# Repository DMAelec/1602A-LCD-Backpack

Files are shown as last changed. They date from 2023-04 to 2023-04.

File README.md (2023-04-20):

# 1602A LCD Backpack

## Introduction
The 1602A LCD Backpack is a AVR(ATMEGA328) microcontroller module that mounts behind standard 16 character x 2 column LCD displays.
It is essentially an Arduino Uno with a built in LCD and some other extra features. The boards are designed using SMD parts
to reduce component size so proper tools are required.

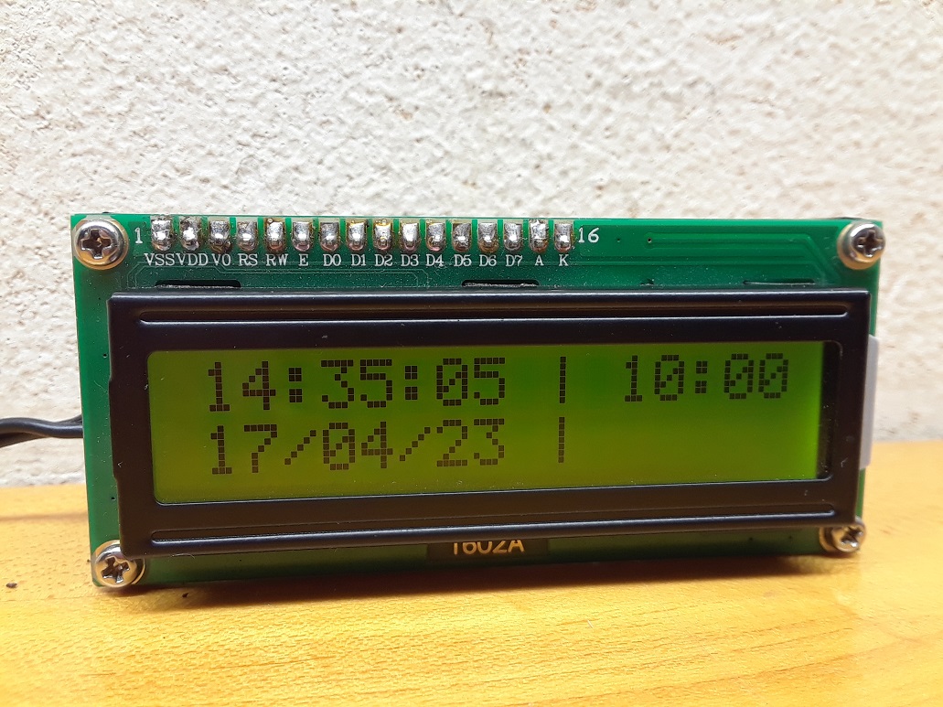
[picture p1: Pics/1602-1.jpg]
1602A Running


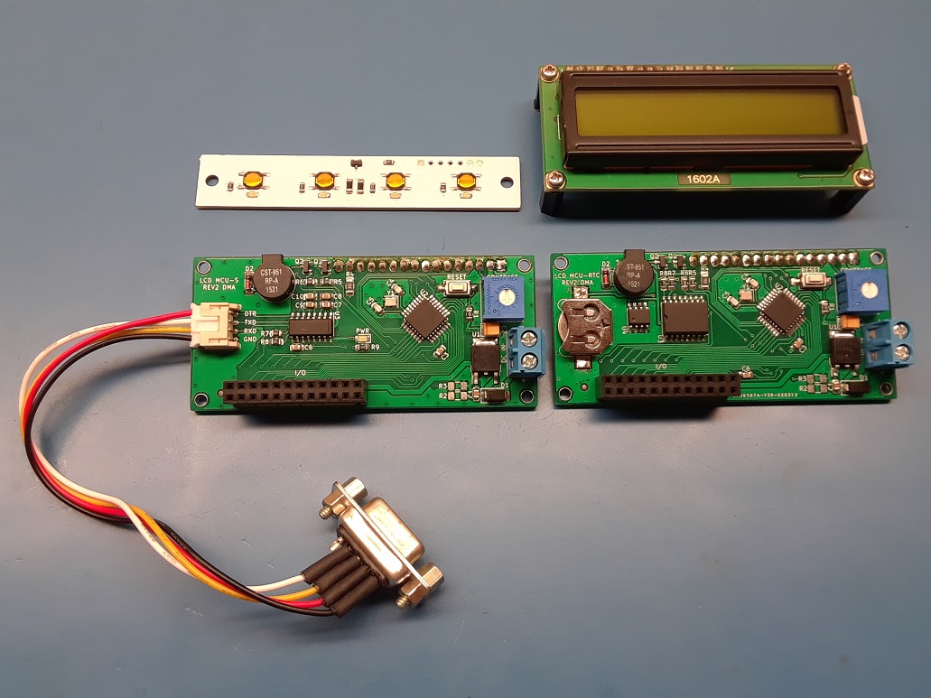
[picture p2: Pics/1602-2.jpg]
1602A Boards


## Features
There are two variants of the backpack in this repo. One with a DS3231 I2C RTC including a I2C EEPROM useful for data logging,
and the other variant with a MAX232 RS232 interface IC. Both boards share features like a optional PWM backlight, speaker, 
and analog volt meter using a simple divider. These can be obmitted if not needed as all pins are brought out to a IO pinheader and
repurposed for other uses. Also included in this repo are external button boards for user input and a blank board for future attachments.

### Board List and features

* 1602A_LCD-RTC Backpack
  * PWM backlight
  * On board speaker
  * Analog voltage monitor
  * I2C real time clock
  * I2C EEPROM

* 1602A_LCD Serial Backpack
  * PWM backlight
  * On board speaker
  * Analog voltage monitor
  * RS232 serial interface with auto reset

* 1602A_Blank
  * Blank board outline for future additions

* BTNPAD_ANALOG_READ
  * Single wire 5 button board using a resistor network

* BTNPAD_TYPE_A
  * 4 button board with pullup resistors

* BTNPAD_TYPE_B
  * 4 button board with pullup resistors
  * LED backlit buttons

## Hardware Documentation

### Schematics

[1602A_LCD-RTC Schematic](/1602A_LCD-RTC%20Backpack/1602A_LCD-RTC%20%20Backpack-SCHEMATIC.pdf)

[1602A_LCD Serial Schematic](/1602A_LCD%20Serial%20Backpack/1602A_LCD%20Serial%20Backpack-SCHEMATIC.pdf)

[BTNPAD_ANALOG_READ Schematic](/Button%20Pad/BTNPAD_ANALOG_READ/BTNPAD_ANALOG_READ-SCHEMATIC.pdf)

[BTNPAD_TYPE_A Schematic](/Button%20Pad/BTNPAD_TYPE_A/BTNPAD_TYPE_A-SCHEMATIC.pdf)

[BTNPAD_TYPE_B Schematic](/Button%20Pad/BTNPAD_TYPE_B/BTNPAD_TYPE_B-SCHEMATIC.pdf)

### IO Pinout

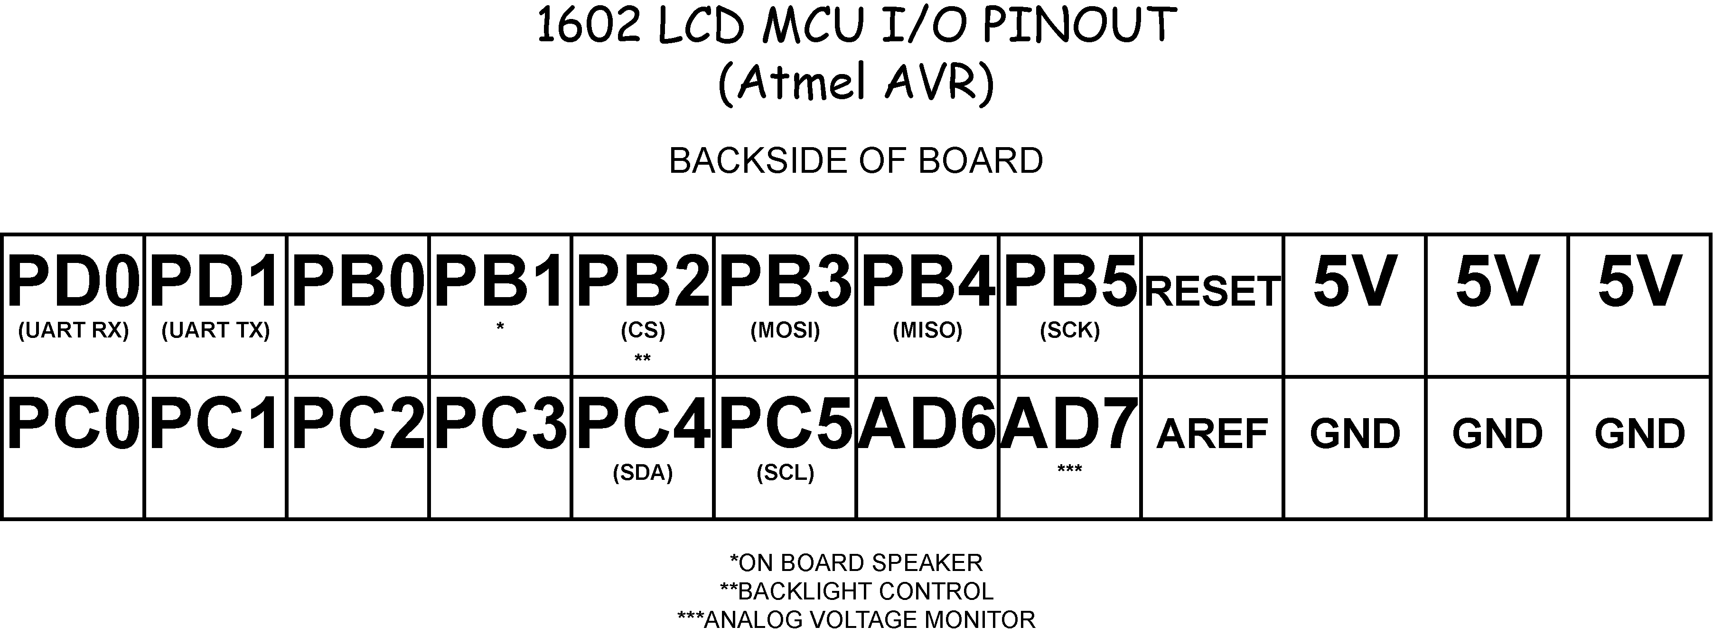
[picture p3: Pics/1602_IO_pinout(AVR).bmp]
1602A AVR IO pinout


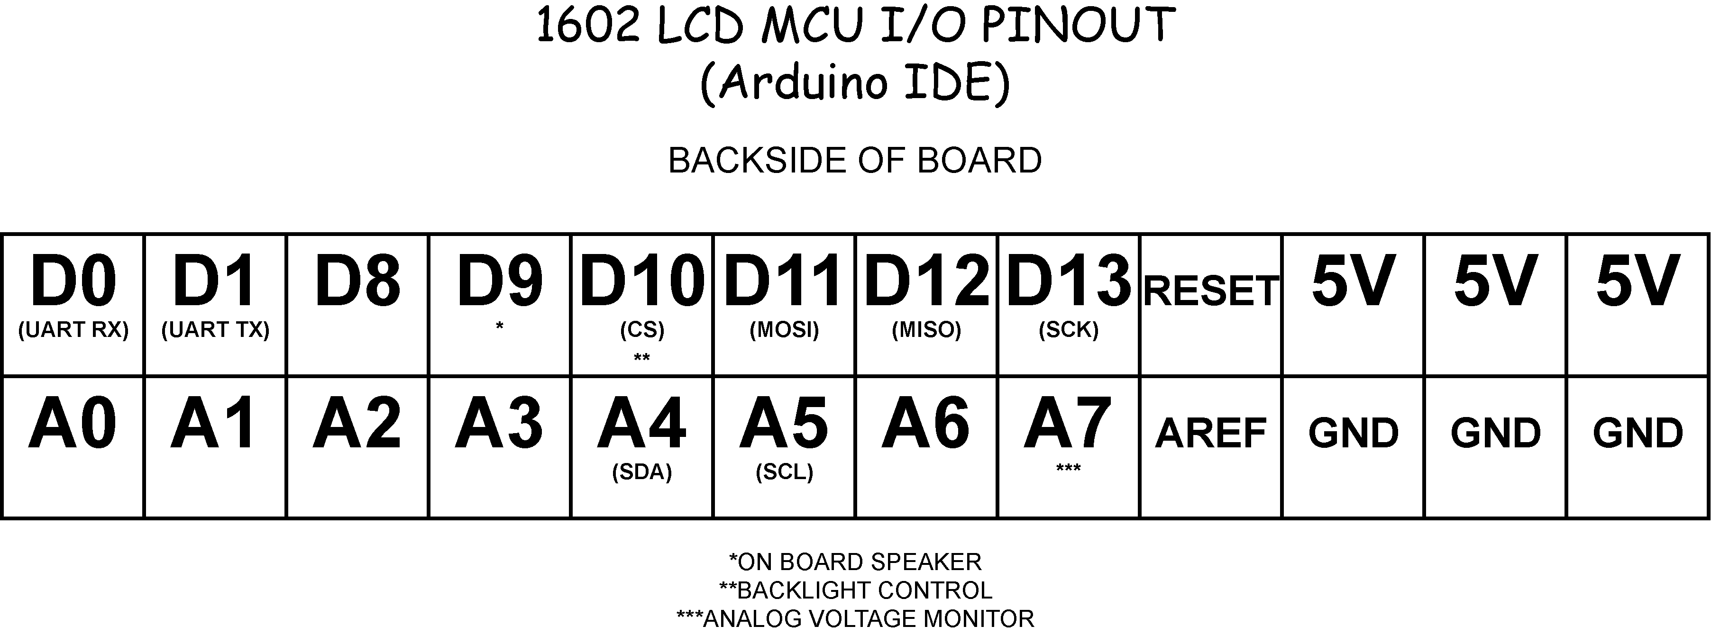
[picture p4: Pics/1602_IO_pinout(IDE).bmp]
1602A IDE IO pinout


### Known Issues

* 1602A_LCD Serial Backpack - REV2
  * Auto reset feature is erratic and may cause latchup
    * Workaround: bodge a 1N4148 diode between +5V and Reset or don't use

* 1602A_LCD - both variants
  * Analog voltage monitoring is after the DC IN protection diode, readings may be inaccurate
    * Workaround: adjust code to account for diode voltage drop

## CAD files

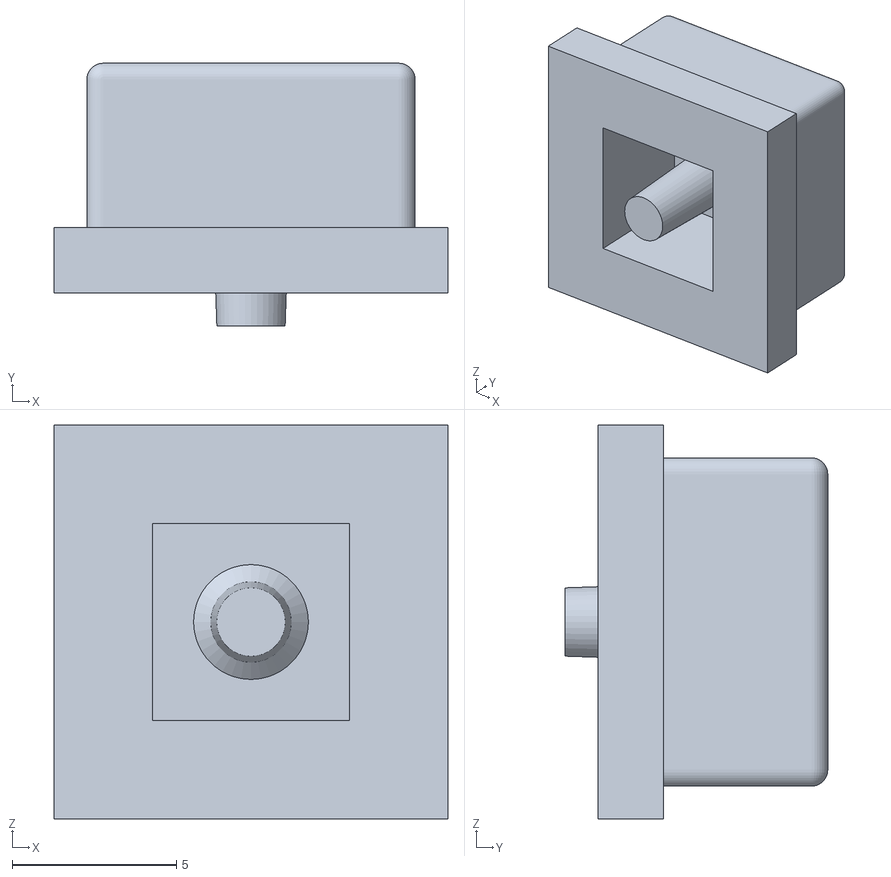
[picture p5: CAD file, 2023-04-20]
1602A_Serpac_Enclosure/1602A_button_cap-square.STL
12.0 x 8.00 x 12.0

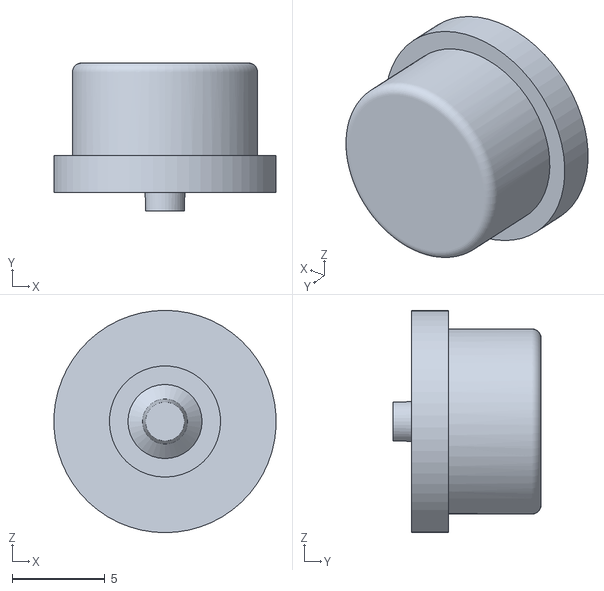
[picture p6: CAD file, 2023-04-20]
1602A_Serpac_Enclosure/1602A_button_cap-round.STL
12.0 x 8.00 x 12.0

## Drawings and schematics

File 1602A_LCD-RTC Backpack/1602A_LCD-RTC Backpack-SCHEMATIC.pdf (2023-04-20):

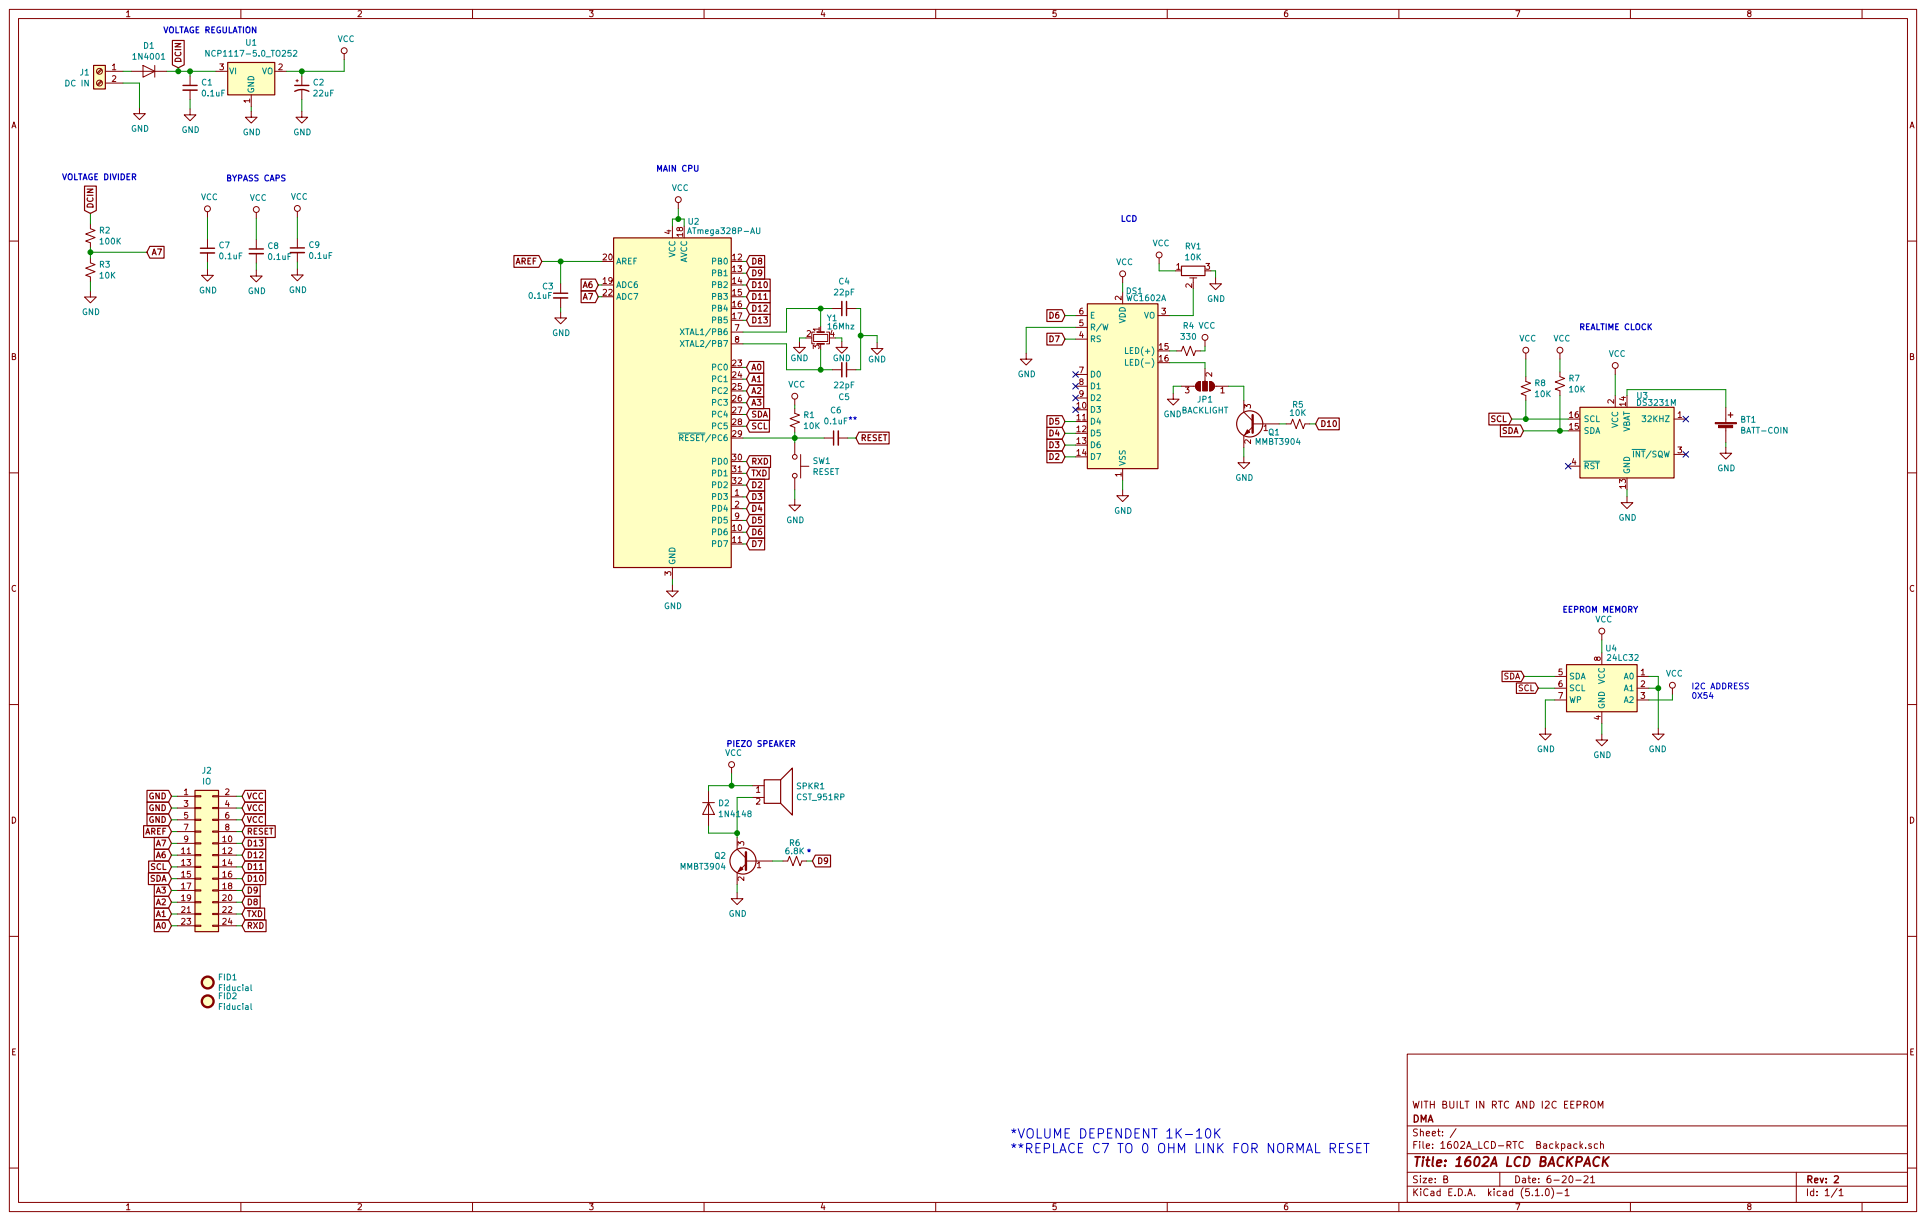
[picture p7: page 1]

4 SDA 5 SCL 6 WP 7 VCC

**REPLACE C7 TO 0 OHM LINK FOR NORMAL RESET

Id: 1/1 Title: 1602A LCD BACKPACK

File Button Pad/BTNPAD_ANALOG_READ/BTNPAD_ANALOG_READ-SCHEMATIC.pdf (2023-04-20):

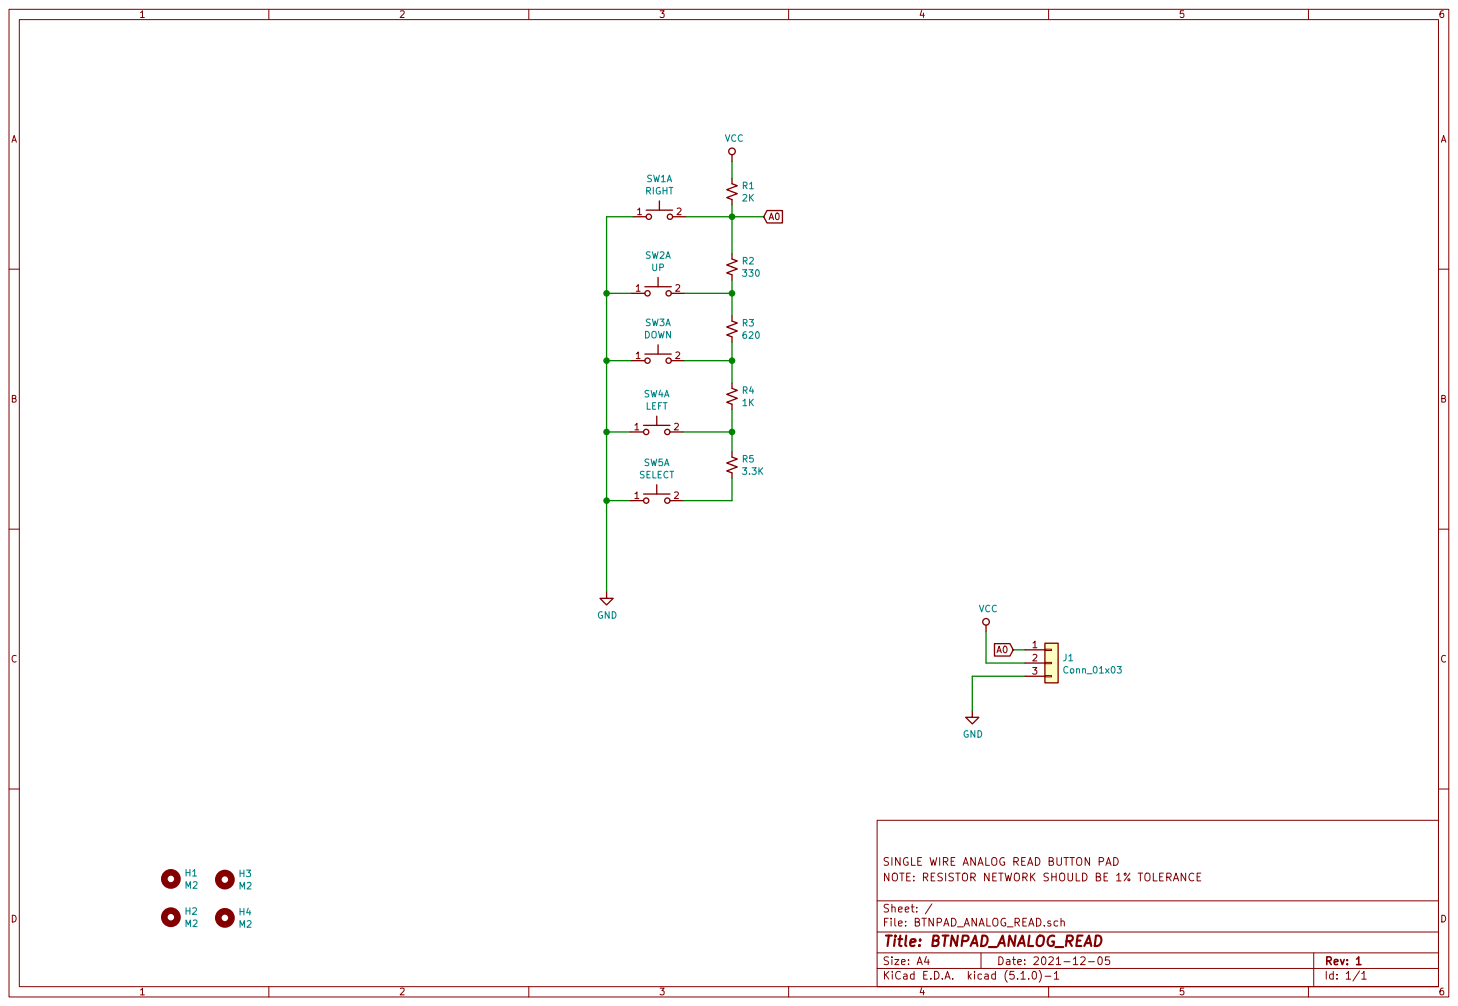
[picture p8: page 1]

SINGLE WIRE ANALOG READ BUTTON PAD
File: BTNPAD_ANALOG_READ.sch Sheet: / NOTE: RESISTOR NETWORK SHOULD BE 1% TOLERANCE

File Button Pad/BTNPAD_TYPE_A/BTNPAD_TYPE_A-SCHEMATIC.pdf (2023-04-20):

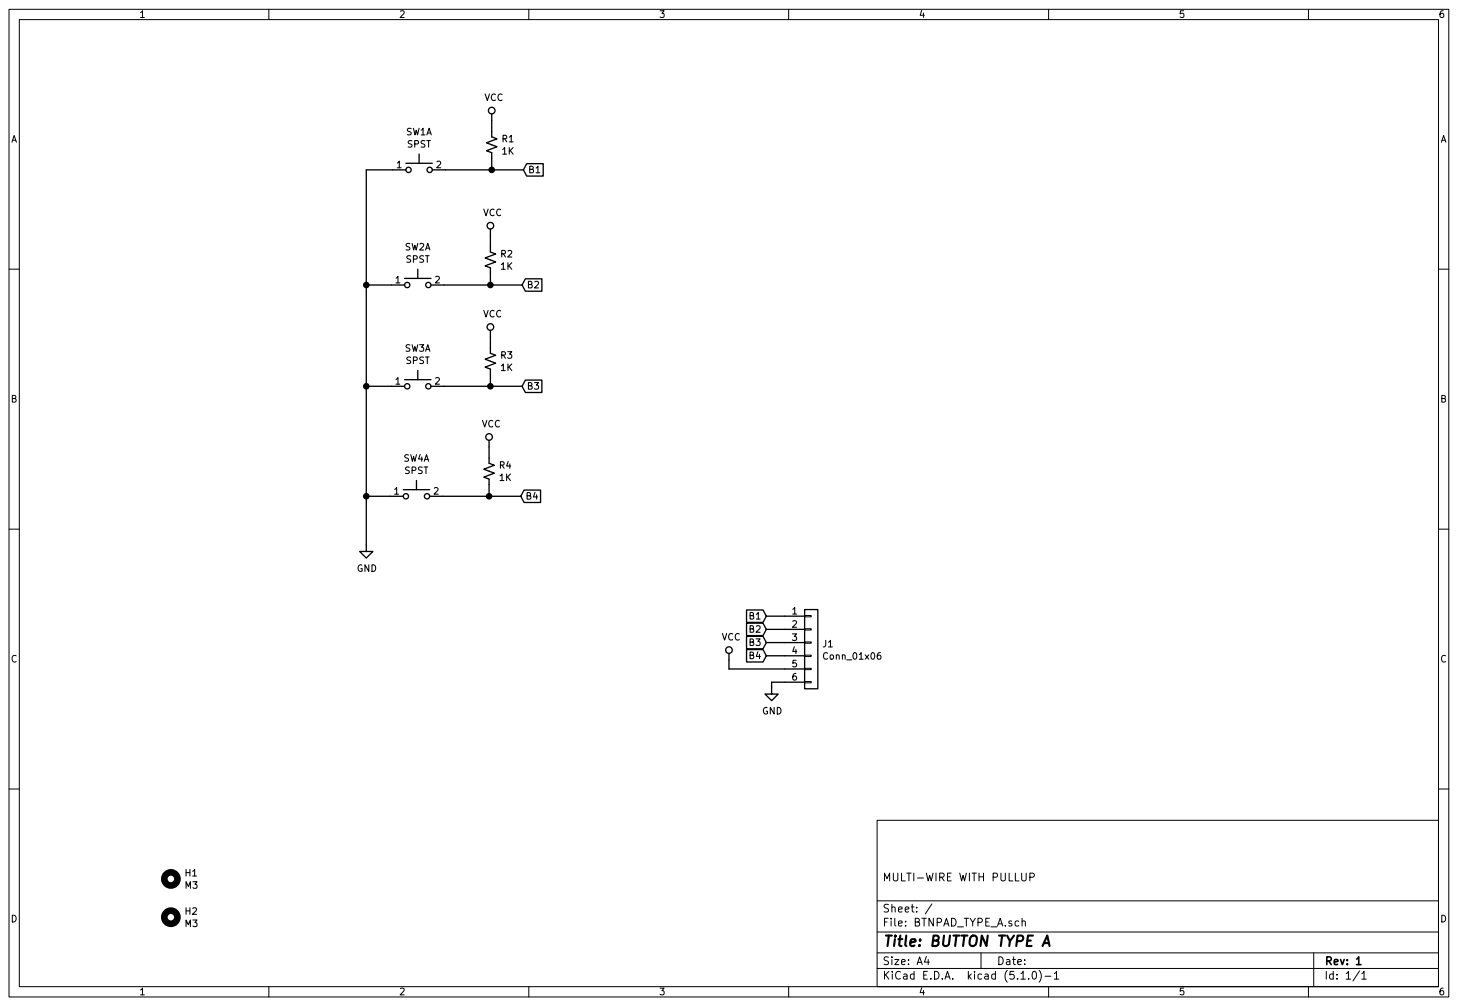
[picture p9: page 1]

File: BTNPAD_TYPE_A.sch Sheet: / MULTI-WIRE WITH PULLUP

Id: 1/1 Title: BUTTON TYPE A

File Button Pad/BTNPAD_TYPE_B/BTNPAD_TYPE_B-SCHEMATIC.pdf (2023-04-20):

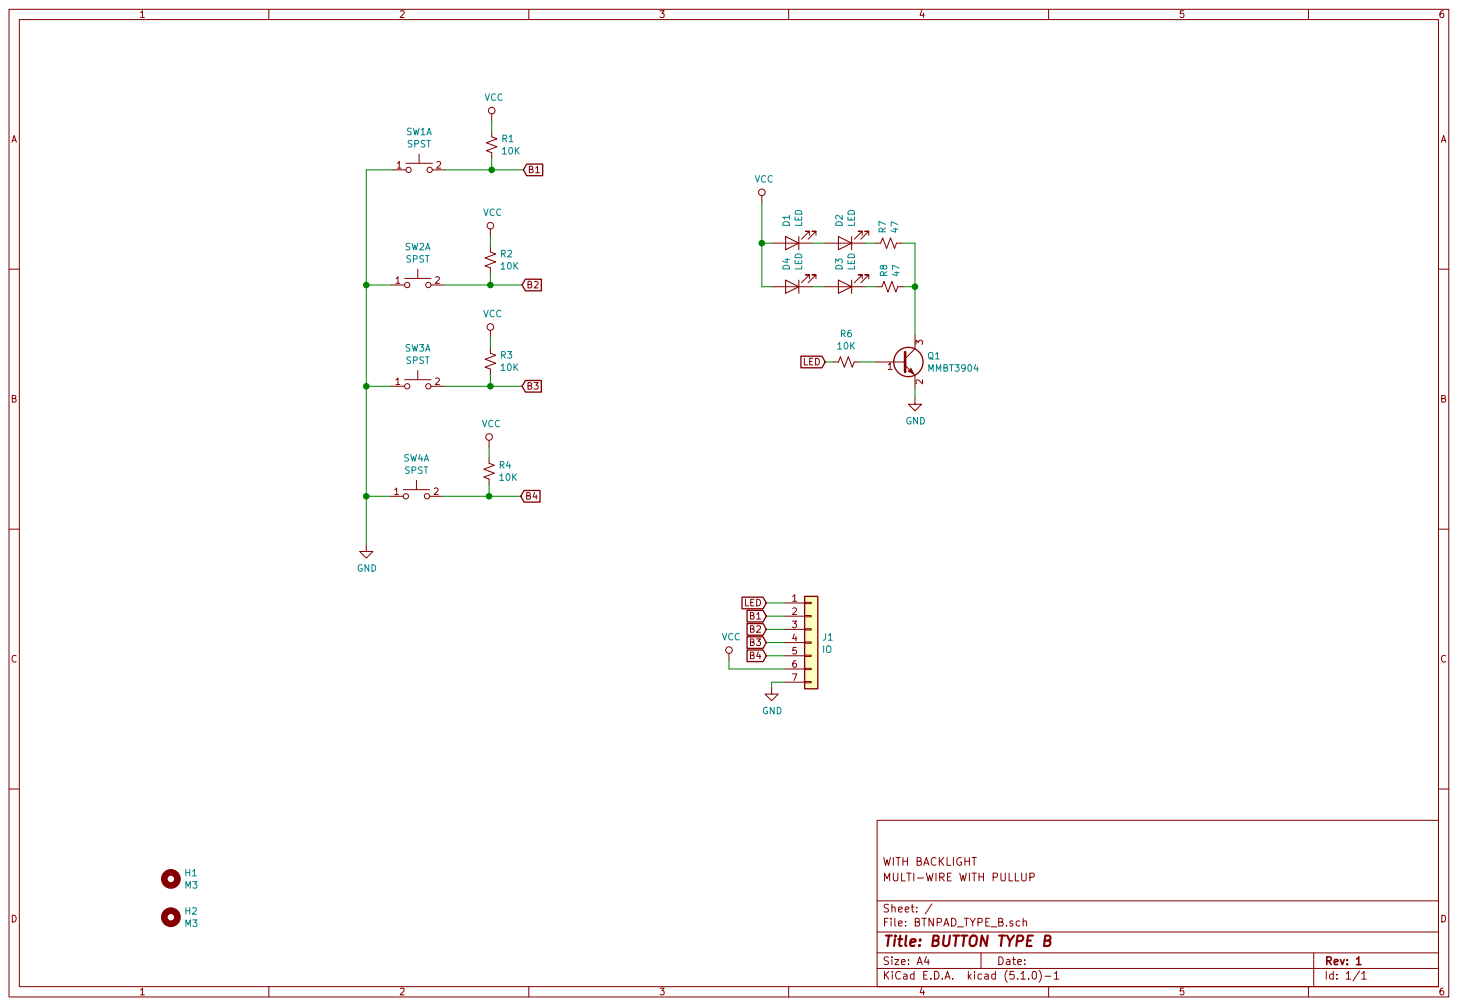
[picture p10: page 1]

File: BTNPAD_TYPE_B.sch Sheet: / MULTI-WIRE WITH PULLUP WITH BACKLIGHT GND

Id: 1/1 Title: BUTTON TYPE B

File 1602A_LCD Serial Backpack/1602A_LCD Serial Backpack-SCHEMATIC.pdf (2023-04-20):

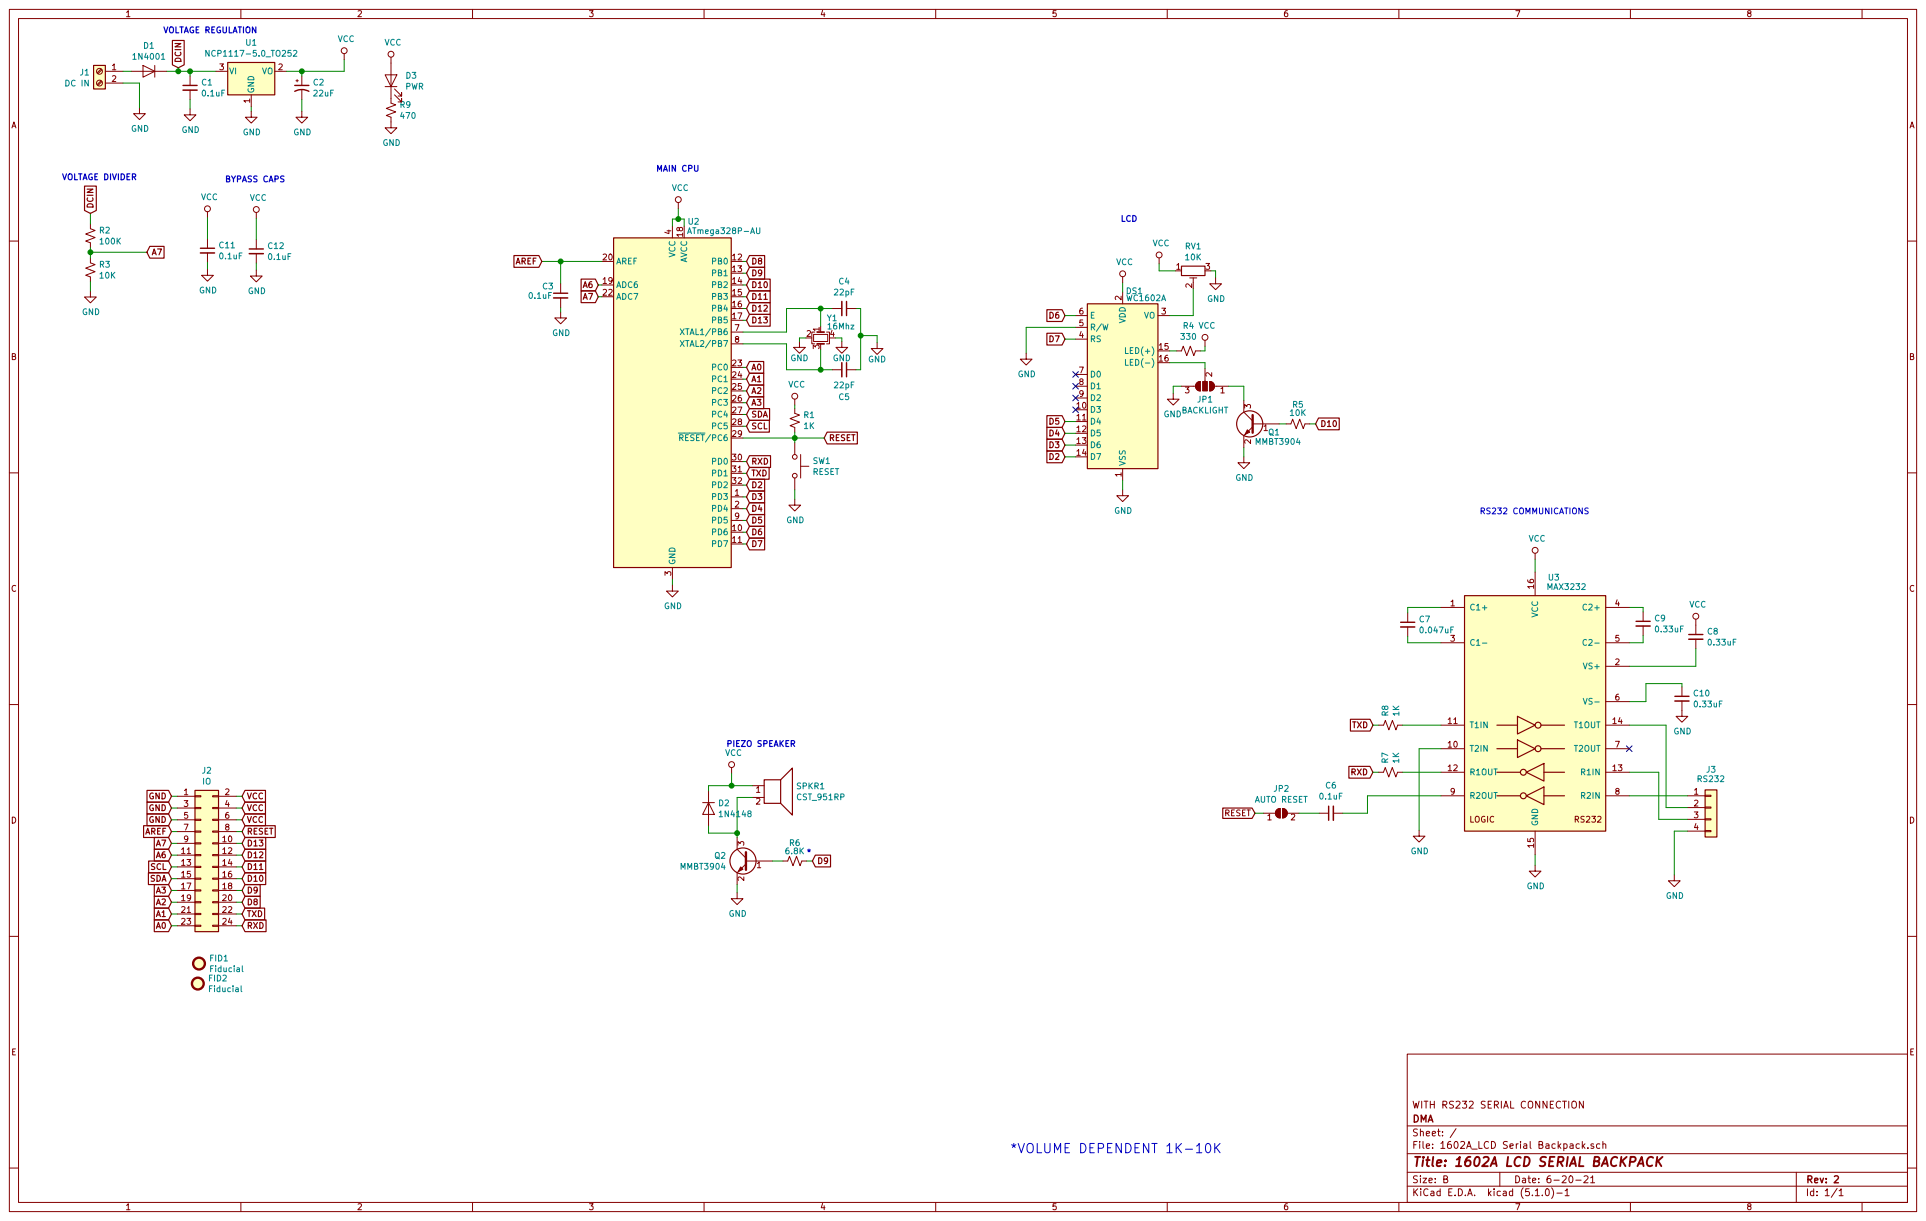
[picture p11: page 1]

Id: 1/1 Title: 1602A LCD SERIAL BACKPACK

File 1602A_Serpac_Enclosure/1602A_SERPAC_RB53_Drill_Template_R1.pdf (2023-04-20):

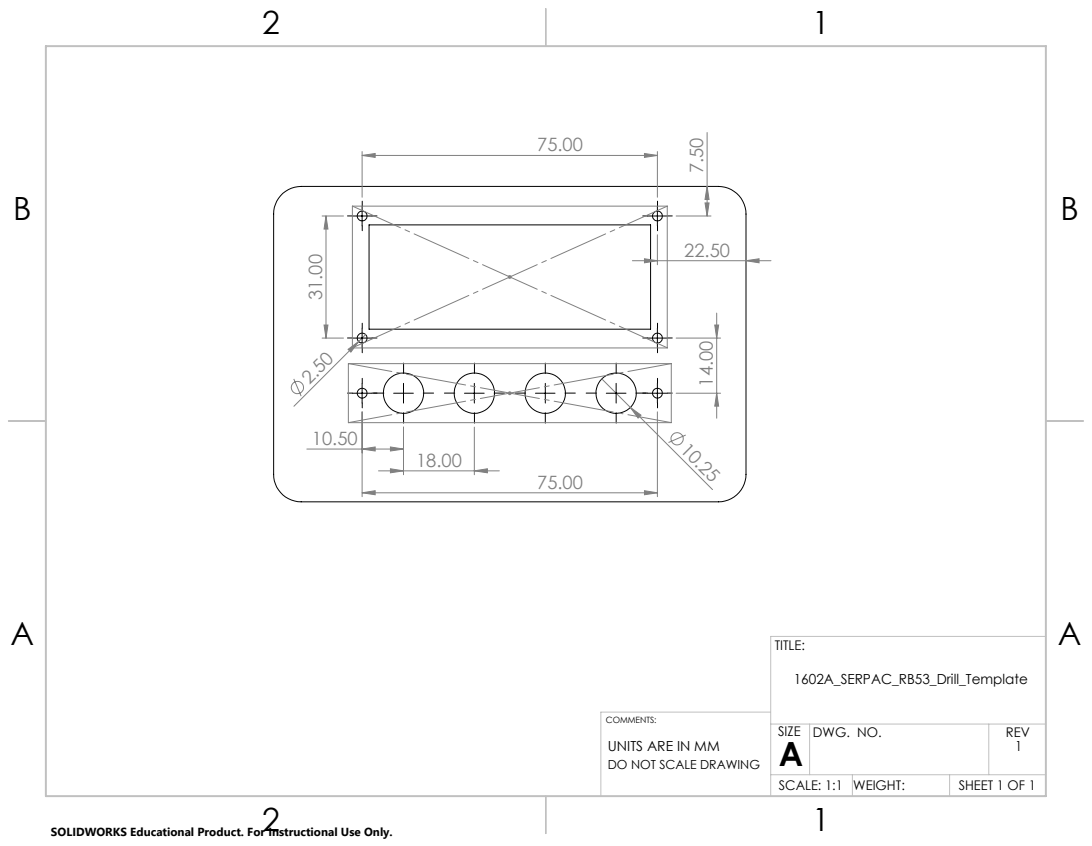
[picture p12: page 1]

COMMENTS:
UNITS ARE IN MM
DO NOT SCALE DRAWING

SIZE A | DWG. NO. | REV 1

SCALE: 1:1 | WEIGHT: | SHEET 1 OF 1

SOLIDWORKS Educational Product. For Instructional Use Only.

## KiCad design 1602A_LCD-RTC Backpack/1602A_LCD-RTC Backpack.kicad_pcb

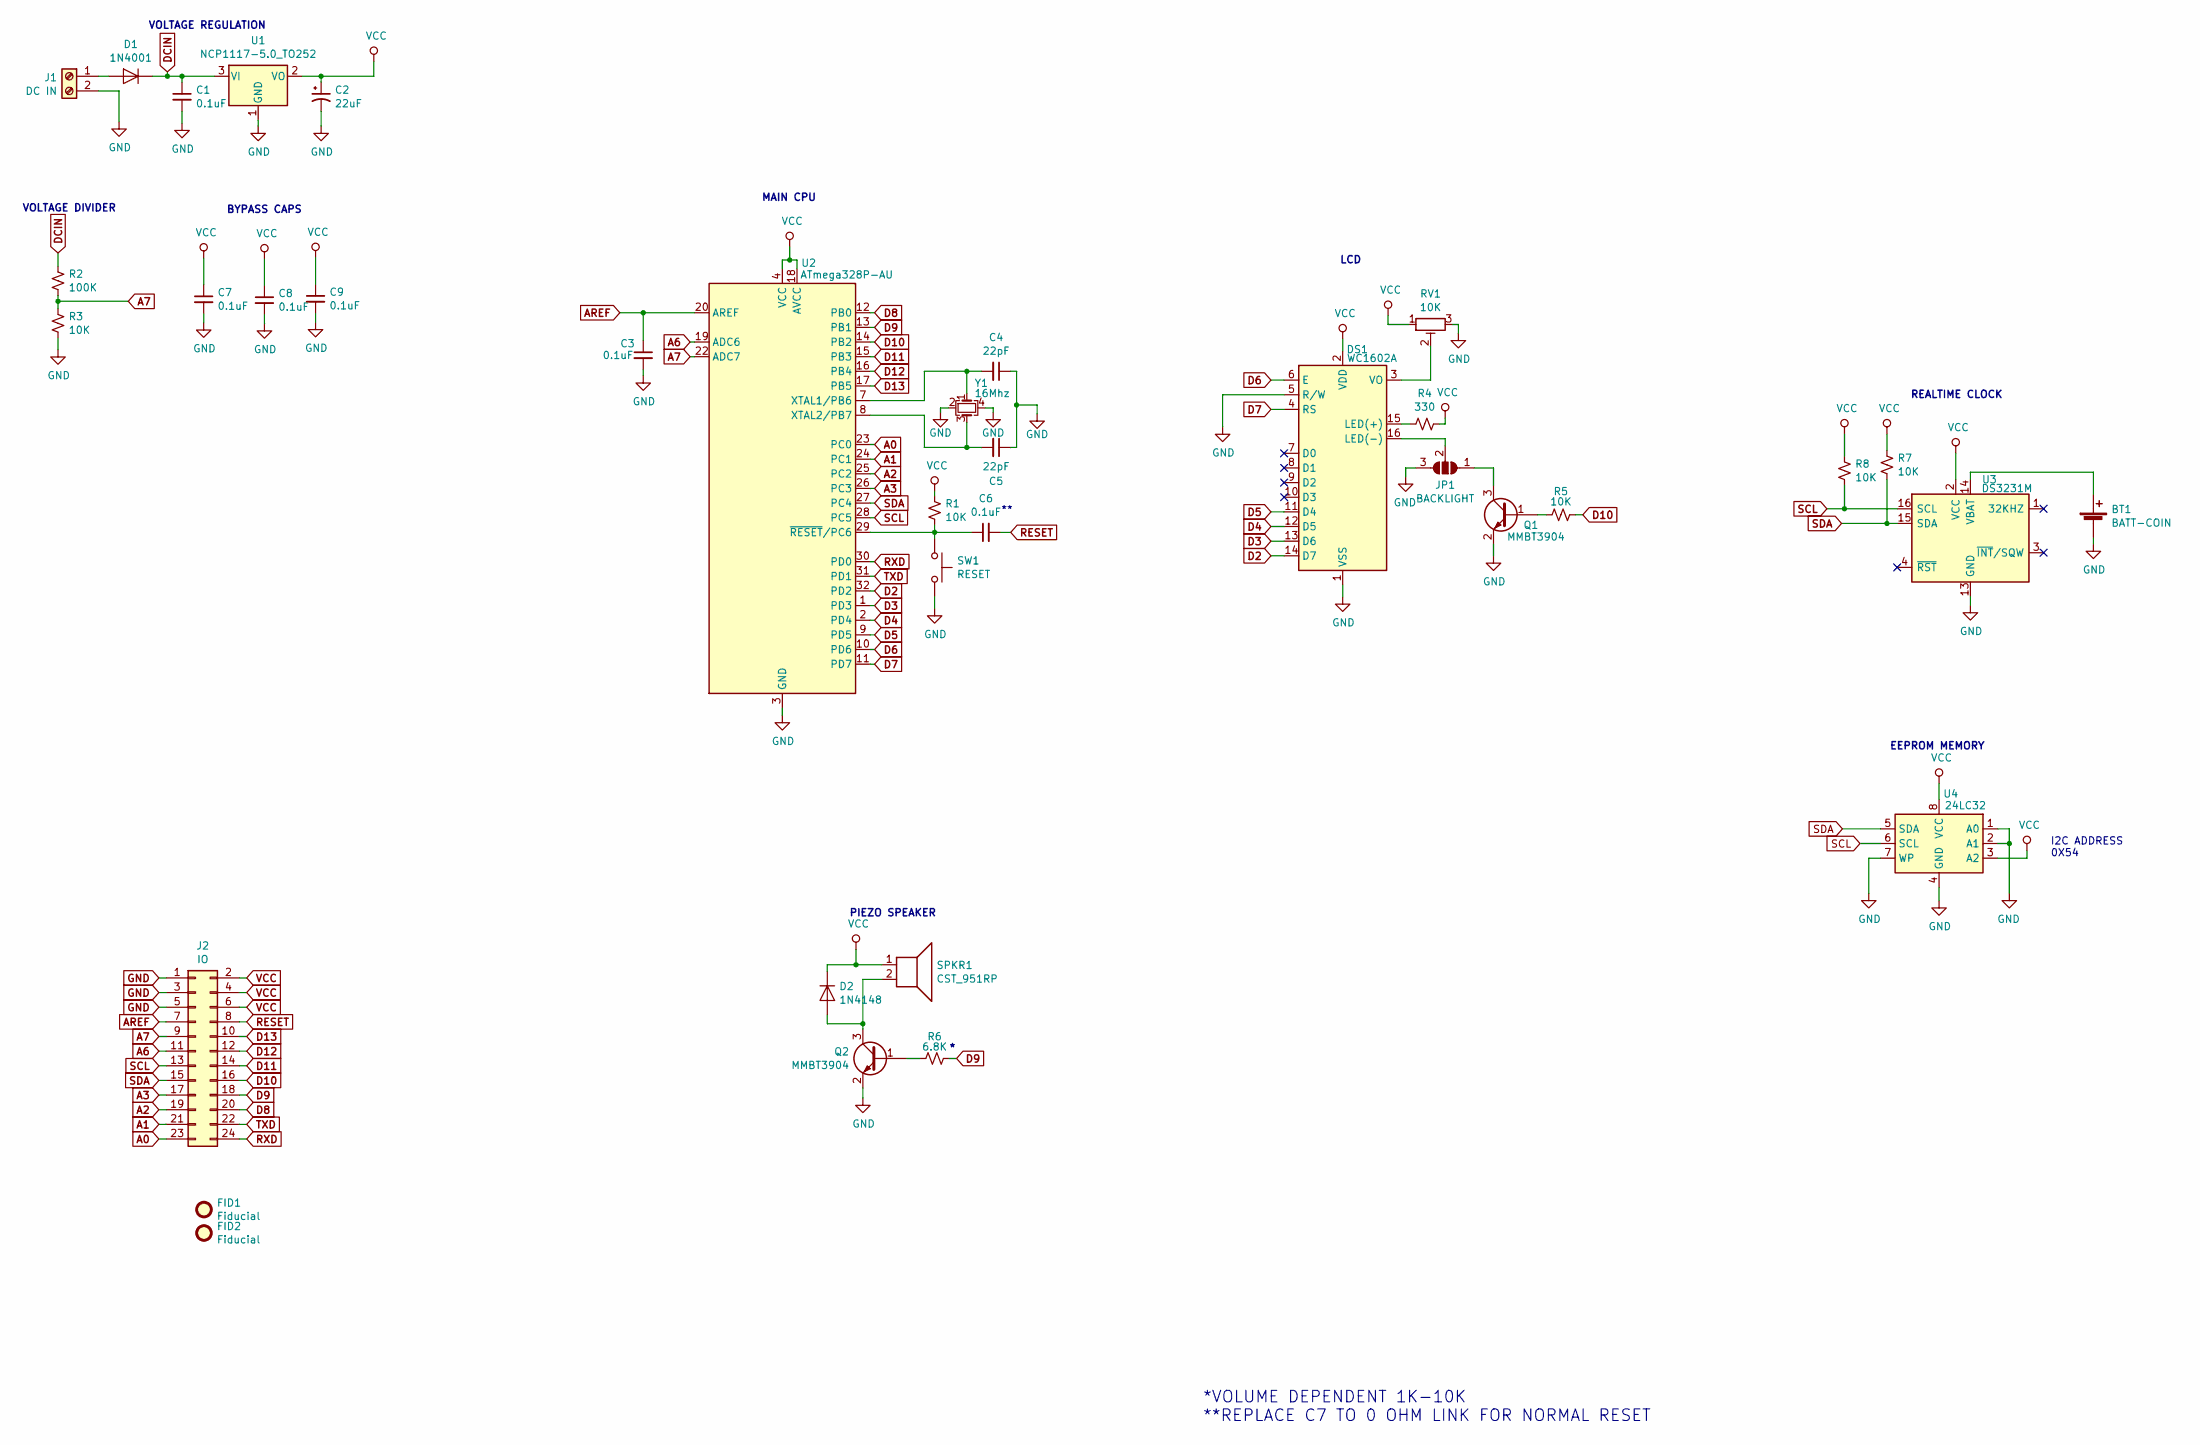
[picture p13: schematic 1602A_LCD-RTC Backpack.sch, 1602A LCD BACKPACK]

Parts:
BT1: BATT-COIN; BatteryHolder_Keystone_3000_1x12mm
C1, C3, C6, C7, C8, C9: 0.1uF; C_0805_2012Metric_Pad1.15x1.40mm_HandSolder
C2: 22uF; CP_EIA-3528-21_Kemet-B
C4, C5: 22pF; C_0805_2012Metric_Pad1.15x1.40mm_HandSolder
D1: 1N4001; D_SMA
D2: 1N4148; D_MiniMELF
DS1: WC1602A
FID1, FID2: Fiducial; Fiducial_1mm_Mask2mm
J1: DC IN; TerminalBlock_bornier-2_P5.08mm
J2: IO; PinSocket_2x12_P2.54mm_Vertical
JP1: BACKLIGHT; SolderJumper-3_P1.3mm_Open_Pad1.0x1.5mm
Q1, Q2: MMBT3904; SOT-23
R1, R5, R7, R8: 10K; R_0805_2012Metric_Pad1.15x1.40mm_HandSolder
R2: 100K; R_1206_3216Metric_Pad1.42x1.75mm_HandSolder
R3: 10K; R_1206_3216Metric_Pad1.42x1.75mm_HandSolder
R4: 330; R_1206_3216Metric_Pad1.42x1.75mm_HandSolder
R6: 6.8K; R_0805_2012Metric_Pad1.15x1.40mm_HandSolder
RV1: 10K; Potentiometer_Bourns_3386P_Vertical
SPKR1: CST_951RP; MagneticBuzzer_CUI_CST-931RP-A
SW1: RESET; SW_SPST_CK_RS282G05A3
U1: NCP1117-5.0_TO252; TO-252-2
U2: ATmega328P-AU; TQFP-32_7x7mm_P0.8mm
U3: DS3231M; SOIC-16W_7.5x10.3mm_P1.27mm
U4: 24LC32; SOIC-8_3.9x4.9mm_P1.27mm
Y1: 16Mhz; Crystal_SMD_2520-4Pin_2.5x2.0mm

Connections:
A0: J2.23, U2.23 (PC0)
A1: J2.21, U2.24 (PC1)
A2: J2.19, U2.25 (PC2)
A3: J2.17, U2.26 (PC3)
A6: J2.11, U2.19 (ADC6)
A7: J2.9, R2.2, R3.1, U2.22 (ADC7)
AREF: C3.1, J2.7, U2.20 (AREF)
D2: DS1.14 (D7), U2.32 (PD2)
D3: DS1.13 (D6), U2.1 (PD3)
D4: DS1.12 (D5), U2.2 (PD4)
D5: DS1.11 (D4), U2.9 (PD5)
D6: DS1.6 (E), U2.10 (PD6)
D7: DS1.4 (RS), U2.11 (PD7)
D8: J2.20, U2.12 (PB0)
D9: J2.18, R6.2, U2.13 (PB1)
D10: J2.16, R5.2, U2.14 (PB2)
D11: J2.14, U2.15 (PB3)
D12: J2.12, U2.16 (PB4)
D13: J2.10, U2.17 (PB5)
DCIN: C1.1, D1.1 (K), R2.1, U1.3 (VI)
GND: BT1.2 (-), C1.2, C2.2, C3.2, C4.1, C5.1, C7.2, C8.2, C9.2, DS1.1 (VSS), DS1.5 (R/W), J1.2, J2.1, J2.3, J2.5, JP1.3 (B), Q1.2 (E), Q2.2 (E), R3.2, RV1.3, SW1.2, U1.1 (GND), U2.3 (GND), U2.5 (GND), U2.21 (GND), U3.5 (GND), U3.6 (GND), U3.7 (GND), U3.8 (GND), U3.9 (GND), U3.10 (GND), U3.11 (GND), U3.12 (GND), U3.13 (GND), U4.1 (A0), U4.2 (A1), U4.4 (GND), U4.7 (WP), Y1.2, Y1.4
unnamed: BT1.1 (+), U3.14 (VBAT)
unnamed: C4.2, U2.7 (XTAL1/PB6), Y1.1
unnamed: C5.2, U2.8 (XTAL2/PB7), Y1.3
unnamed: C6.1, R1.2, SW1.1, U2.29 (~RESET~/PC6)
unnamed: D1.2 (A), J1.1
unnamed: D2.2 (A), Q2.3 (C), SPKR1.2
unnamed: DS1.3 (VO), RV1.2
unnamed: DS1.15 (LED(+)), R4.1
unnamed: DS1.16 (LED(-)), JP1.2 (C)
unnamed: JP1.1 (A), Q1.3 (C)
unnamed: Q1.1 (B), R5.1
unnamed: Q2.1 (B), R6.1
RESET: C6.2, J2.8
RXD: J2.24, U2.30 (PD0)
SCL: J2.13, R8.2, U2.28 (PC5), U3.16 (SCL), U4.6 (SCL)
SDA: J2.15, R7.2, U2.27 (PC4), U3.15 (SDA), U4.5 (SDA)
TXD: J2.22, U2.31 (PD1)
VCC: C2.1, C7.1, C8.1, C9.1, D2.1 (K), DS1.2 (VDD), J2.2, J2.4, J2.6, R1.1, R4.2, R7.1, R8.1, RV1.1, SPKR1.1, U1.2 (VO), U2.4 (VCC), U2.6 (VCC), U2.18 (AVCC), U3.2 (VCC), U4.3 (A2), U4.8 (VCC)

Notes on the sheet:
VOLTAGE REGULATION
BYPASS CAPS
VOLTAGE DIVIDER
LCD
REALTIME CLOCK
PIEZO SPEAKER
MAIN CPU
*VOLUME DEPENDENT 1K-10K **REPLACE C7 TO 0 OHM LINK FOR NORMAL RESET
EEPROM MEMORY
I2C ADDRESS 0X54

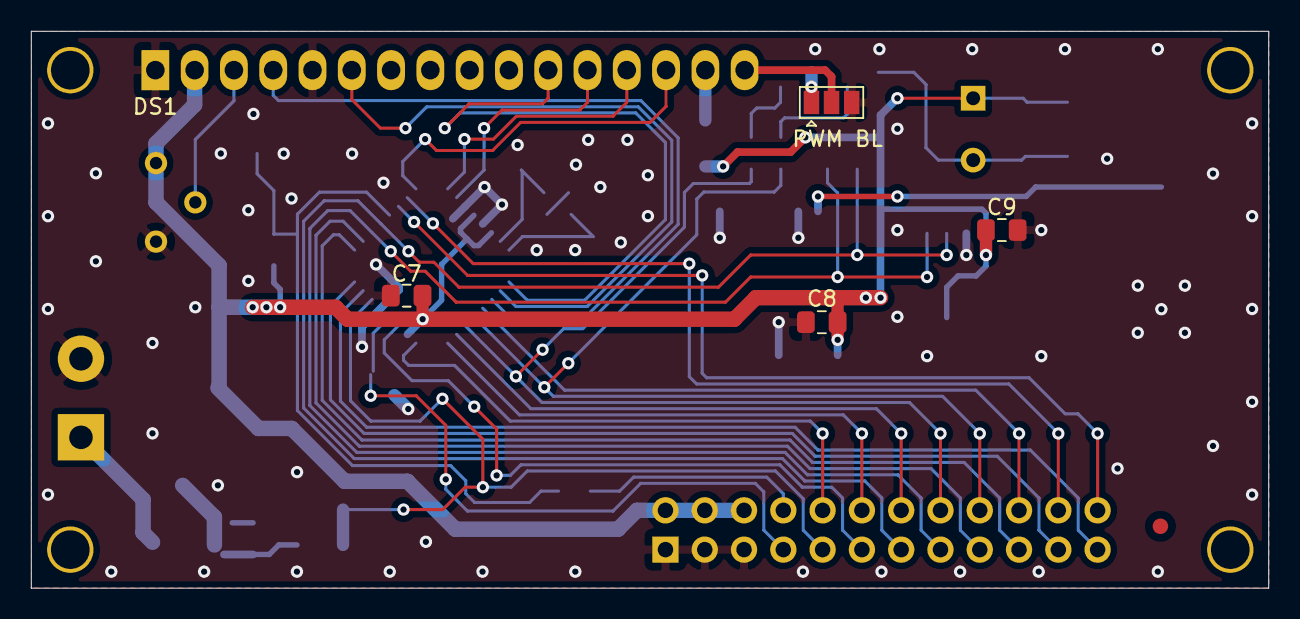
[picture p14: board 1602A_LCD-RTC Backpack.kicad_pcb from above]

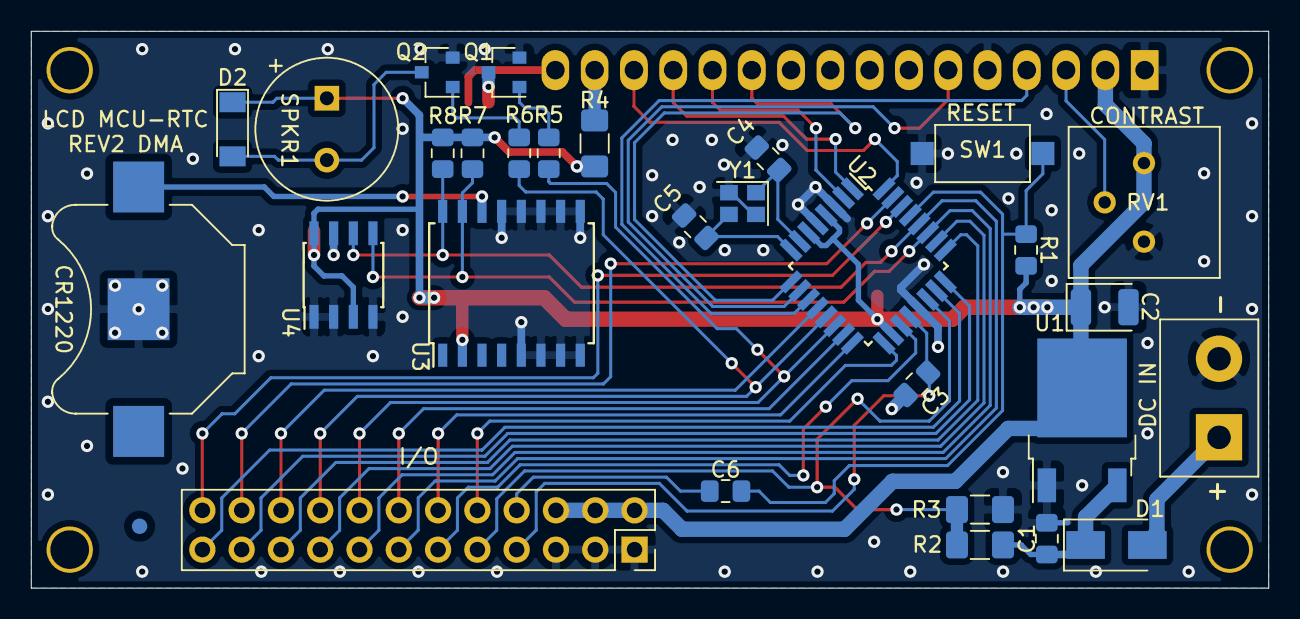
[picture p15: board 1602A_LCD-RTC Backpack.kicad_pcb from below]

Board: 2 copper layers, 80.0 x 36.0 mm, 36 parts (30 on the bottom side), 39 nets.

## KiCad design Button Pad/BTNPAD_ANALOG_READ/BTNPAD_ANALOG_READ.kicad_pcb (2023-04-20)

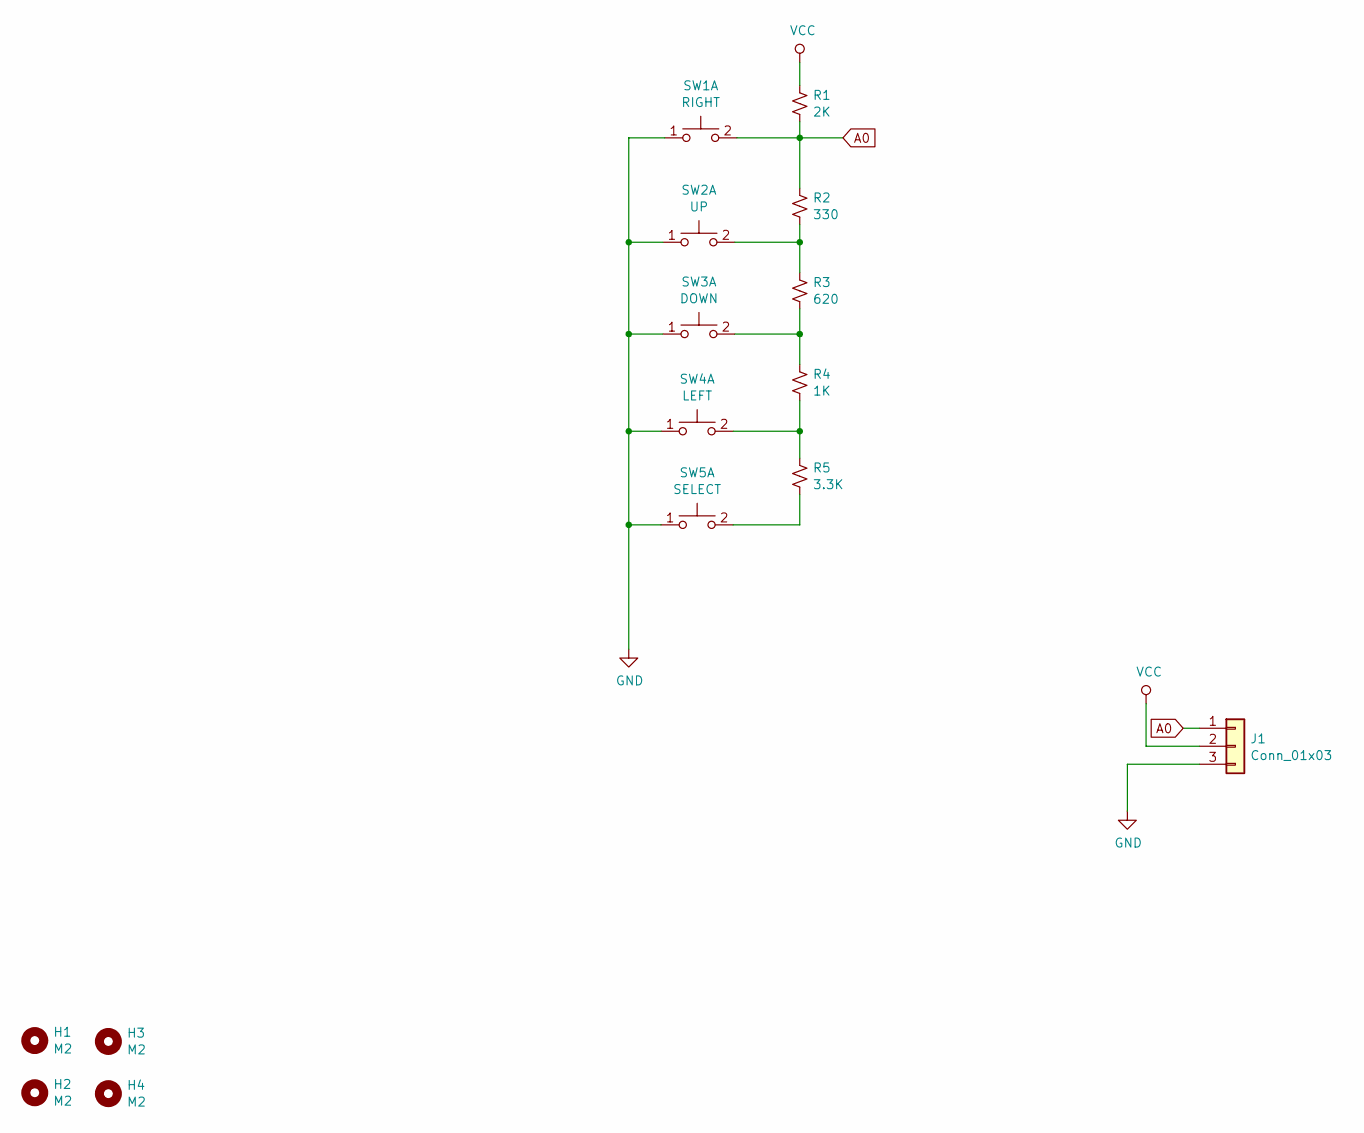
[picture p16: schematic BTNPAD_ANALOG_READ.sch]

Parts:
H1, H2, H3, H4: M2; MountingHole_2.5mm
J1: Conn_01x03; PinHeader_1x03_P2.54mm_Vertical
R1: 2K; R_0805_2012Metric_Pad1.15x1.40mm_HandSolder
R2: 330; R_0805_2012Metric_Pad1.15x1.40mm_HandSolder
R3: 620; R_0805_2012Metric_Pad1.15x1.40mm_HandSolder
R4: 1K; R_0805_2012Metric_Pad1.15x1.40mm_HandSolder
R5: 3.3K; R_0805_2012Metric_Pad1.15x1.40mm_HandSolder
SW1: RIGHT; SW_SPST_CK_RS282G05A3
SW2: UP; SW_SPST_CK_RS282G05A3
SW3: DOWN; SW_SPST_CK_RS282G05A3
SW4: LEFT; SW_SPST_CK_RS282G05A3
SW5: SELECT; SW_SPST_CK_RS282G05A3

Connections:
A0: J1.1, R1.2, R2.1, SW1.2 (D)
GND: J1.3, SW1.1 (C), SW2.1 (C), SW3.1 (C), SW4.1 (C), SW5.1 (C)
unnamed: R2.2, R3.1, SW2.2 (D)
unnamed: R3.2, R4.1, SW3.2 (D)
unnamed: R4.2, R5.1, SW4.2 (D)
unnamed: R5.2, SW5.2 (D)
VCC: J1.2, R1.1

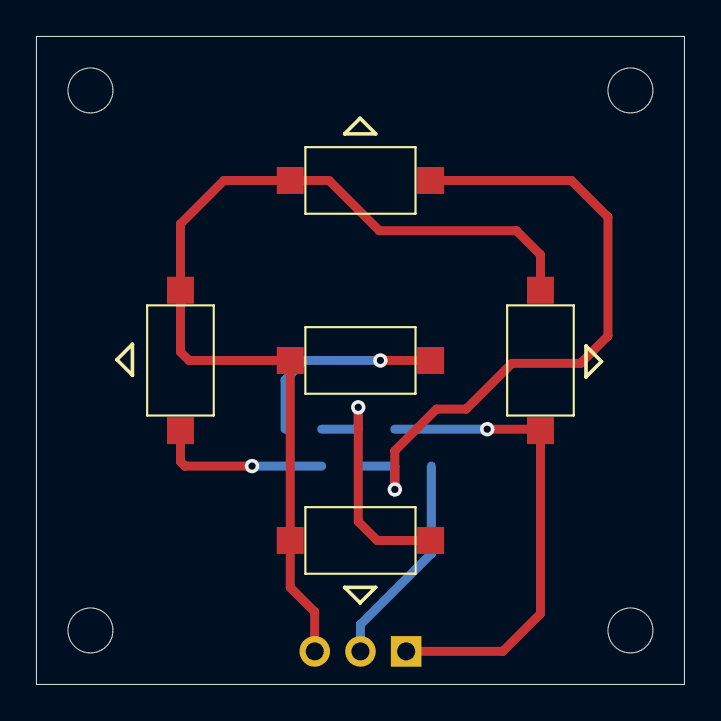
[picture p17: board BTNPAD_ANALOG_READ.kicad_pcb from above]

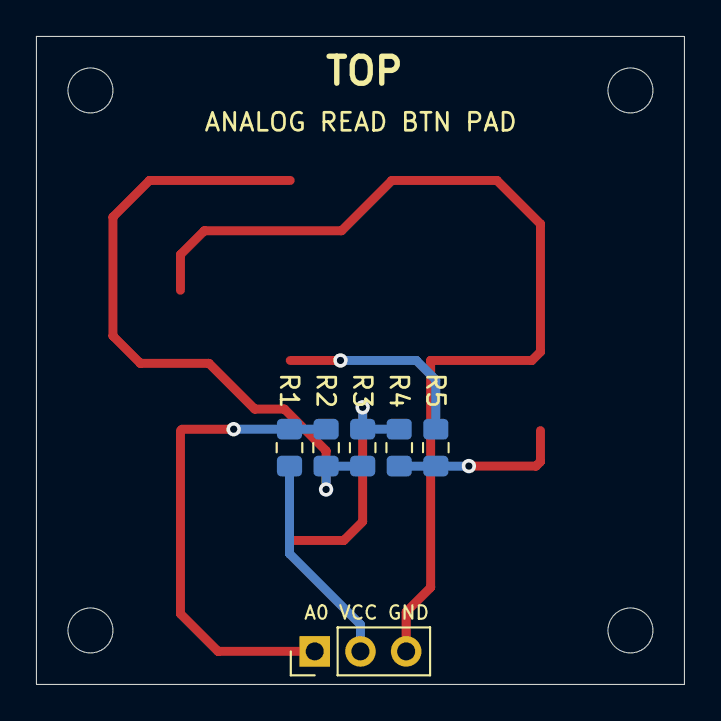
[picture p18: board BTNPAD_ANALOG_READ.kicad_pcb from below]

Board: 2 copper layers, 36.0 x 36.0 mm, 15 parts (6 on the bottom side), 7 nets.

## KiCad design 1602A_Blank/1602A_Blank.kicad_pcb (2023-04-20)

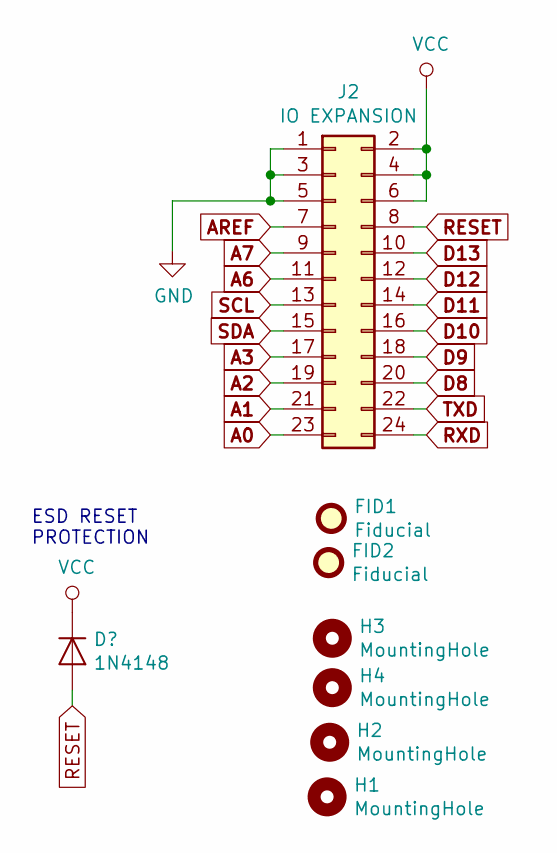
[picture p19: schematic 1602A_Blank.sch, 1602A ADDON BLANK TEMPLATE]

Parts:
FID1, FID2: Fiducial; Fiducial_1mm_Mask2mm
H1, H2, H3, H4: MountingHole; MountingHole_2.5mm_Pad
J2: IO EXPANSION; PinSocket_2x12_P2.54mm_Vertical

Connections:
A0: J2.23
A1: J2.21
A2: J2.19
A3: J2.17
A6: J2.11
A7: J2.9
AREF: J2.7
D8: J2.20
D9: J2.18
D10: J2.16
D11: J2.14
D12: J2.12
D13: J2.10
GND: J2.1, J2.3, J2.5
RESET: J2.8
RXD: J2.22
SCL: J2.13
SDA: J2.15
TXD: J2.24
VCC: J2.2, J2.4, J2.6

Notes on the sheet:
ESD RESET PROTECTION

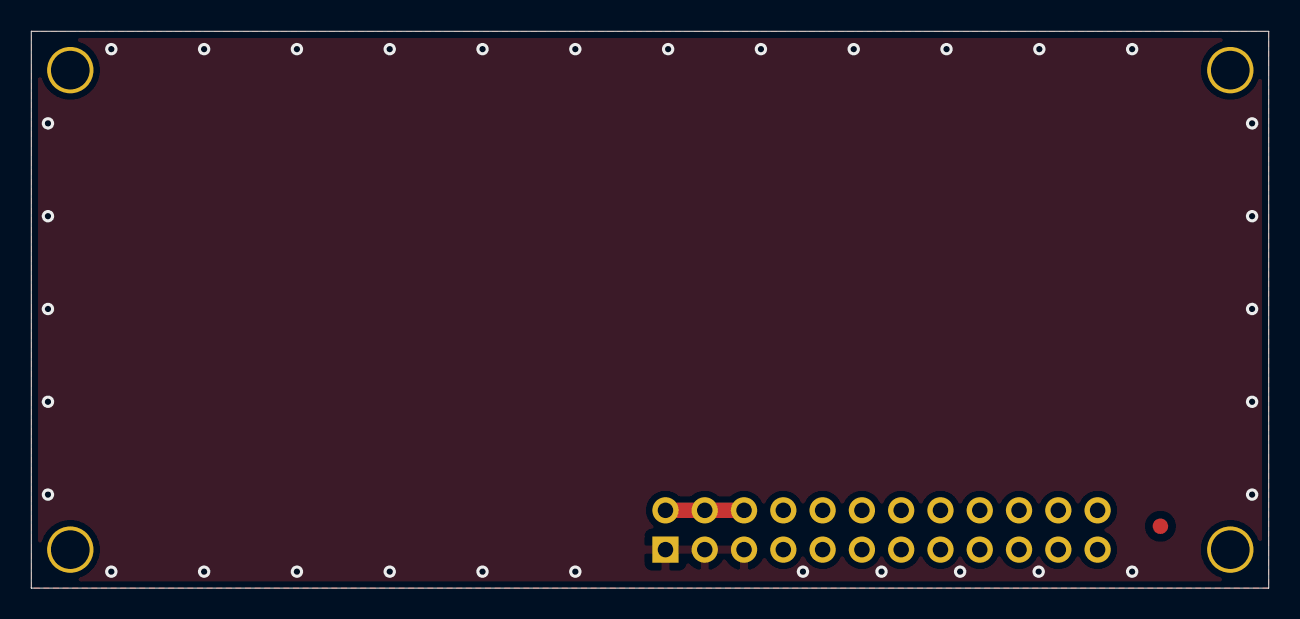
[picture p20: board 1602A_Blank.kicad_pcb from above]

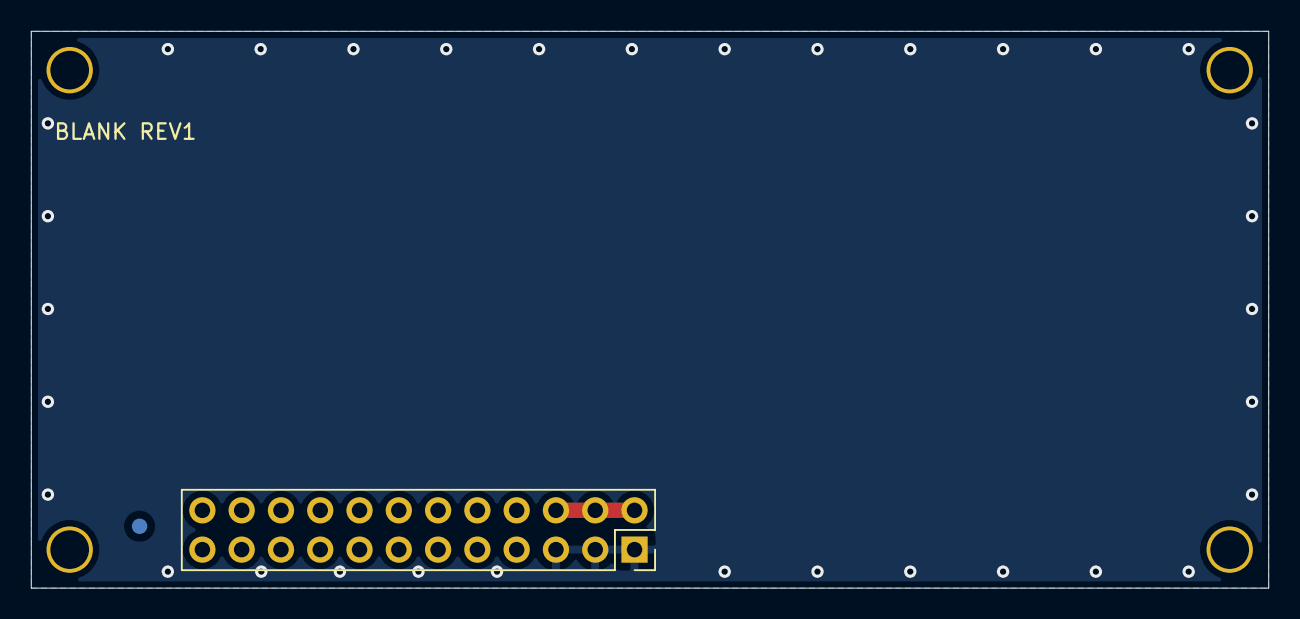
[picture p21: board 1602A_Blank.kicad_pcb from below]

Board: 2 copper layers, 80.0 x 36.0 mm, 7 parts (2 on the bottom side), 2 nets.

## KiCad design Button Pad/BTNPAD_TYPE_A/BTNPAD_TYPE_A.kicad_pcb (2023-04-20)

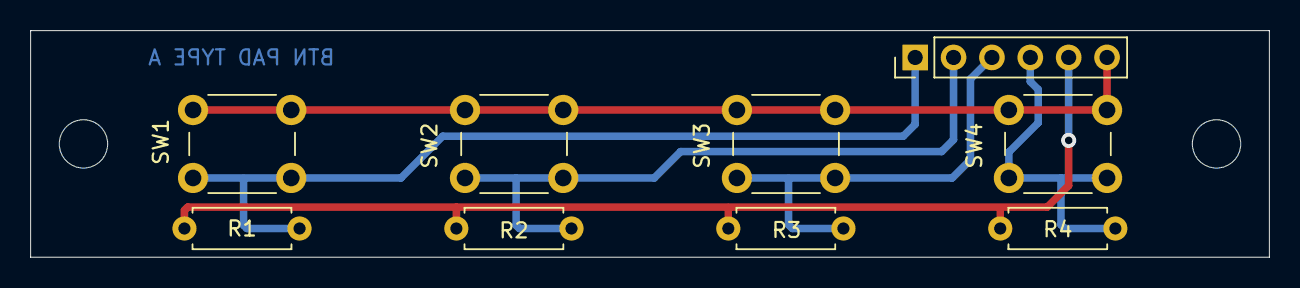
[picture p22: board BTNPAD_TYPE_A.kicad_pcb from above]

Board: 2 copper layers, 82.0 x 15.0 mm, 11 parts (0 on the bottom side), 6 nets.

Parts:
H1, H2: M3; MountingHole_3.2mm_M3
J1: Conn_01x06; PinHeader_1x06_P2.54mm_Vertical
R1, R2, R3, R4: 10K; R_Axial_DIN0207_L6.3mm_D2.5mm_P7.62mm_Horizontal
SW1, SW2, SW3, SW4: SPST; SW_PUSH_6mm

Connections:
B1: J1.1, R1.2, SW1.2
B2: J1.2, R2.2, SW2.2
B3: J1.3, R3.2, SW3.2
B4: J1.4, R4.2, SW4.2
GND: J1.6, SW1.1, SW2.1, SW3.1, SW4.1
VCC: J1.5, R1.1, R2.1, R3.1, R4.1

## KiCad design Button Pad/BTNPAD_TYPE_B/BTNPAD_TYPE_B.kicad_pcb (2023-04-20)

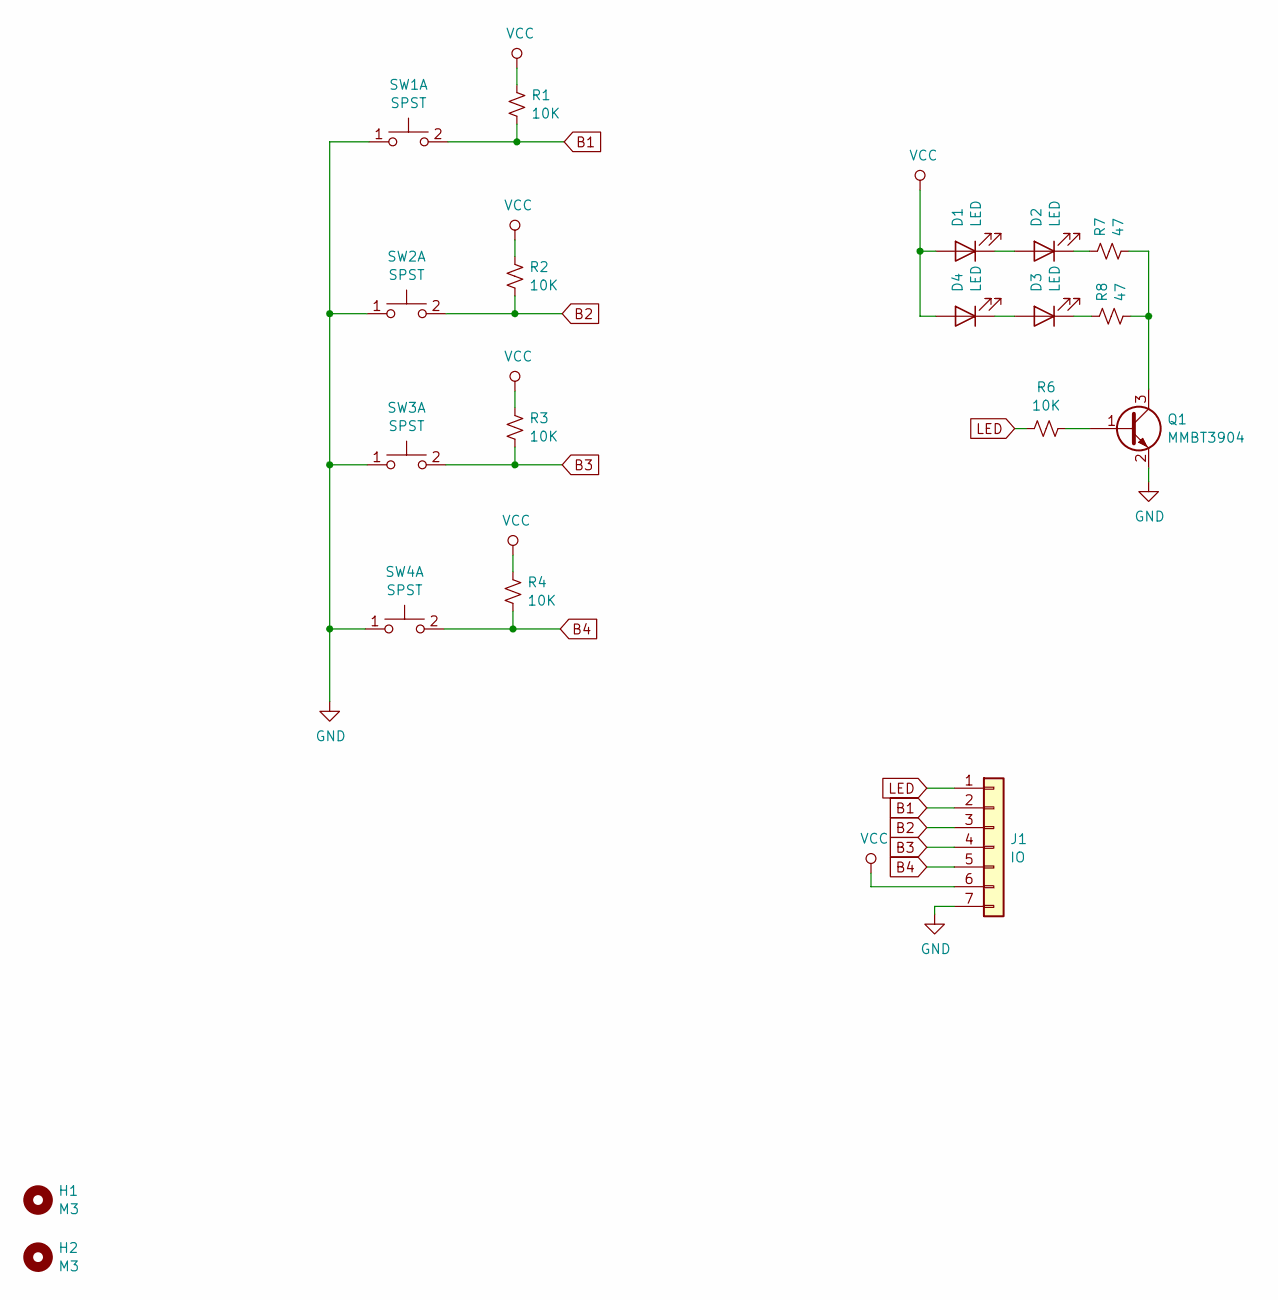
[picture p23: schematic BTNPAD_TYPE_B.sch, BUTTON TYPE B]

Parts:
D1, D2, D3, D4: LED; LED_0805_2012Metric_Pad1.15x1.40mm_HandSolder
H1, H2: M3; MountingHole_3.2mm_M3
J1: IO; PinHeader_1x07_P2.54mm_Vertical
Q1: MMBT3904; SOT-23
R1, R2, R3, R4, R6: 10K; R_0805_2012Metric_Pad1.15x1.40mm_HandSolder
R7, R8: 47; R_1206_3216Metric_Pad1.42x1.75mm_HandSolder
SW1, SW2, SW3, SW4: SPST; SW_SPST_TL3342

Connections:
B1: J1.2, R1.2, SW1.2 (D)
B2: J1.3, R2.2, SW2.2 (D)
B3: J1.4, R3.2, SW3.2 (D)
B4: J1.5, R4.2, SW4.2 (D)
GND: J1.7, Q1.2 (E), SW1.1 (C), SW2.1 (C), SW3.1 (C), SW4.1 (C)
LED: J1.1, R6.1
unnamed: D1.1 (K), D2.2 (A)
unnamed: D2.1 (K), R7.1
unnamed: D3.1 (K), R8.1
unnamed: D3.2 (A), D4.1 (K)
unnamed: Q1.1 (B), R6.2
unnamed: Q1.3 (C), R7.2, R8.2
VCC: D1.2 (A), D4.2 (A), J1.6, R1.1, R2.1, R3.1, R4.1

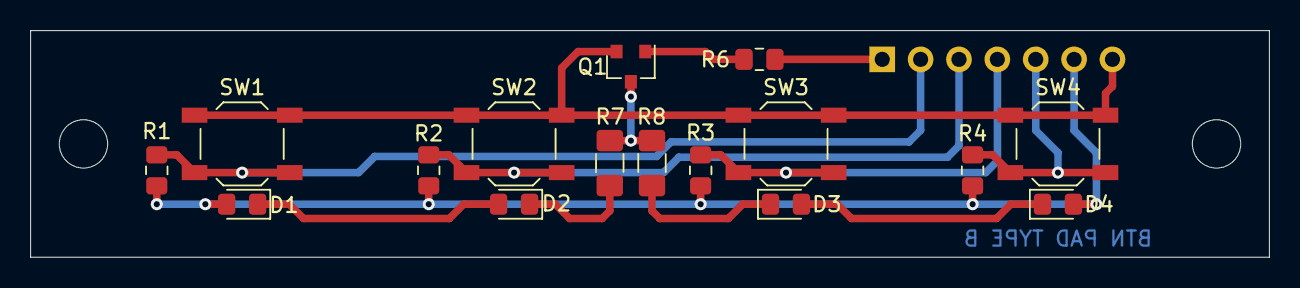
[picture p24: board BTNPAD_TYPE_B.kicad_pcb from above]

Board: 2 copper layers, 82.0 x 15.0 mm, 19 parts (1 on the bottom side), 13 nets.
